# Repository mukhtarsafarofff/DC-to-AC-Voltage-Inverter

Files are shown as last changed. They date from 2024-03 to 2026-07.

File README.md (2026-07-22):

(ENG)  This Power Inverter is a backup power supply using a 12V battery that will invert it to 220V AC. Using this Power Inverter we can use your appliances like TV, Radio, Audio system as well as lightings like a bulb, fluorescent, etc. This inverter has three main parts: 12V Battery, Inverter Board, and Centertapped Transformer. This inverter has a Tl494 PWM IC that provides a pulse with modulation, the two output pins of this PWM ic are responsible for ON state and OFF state of the power mosfet. Power Mosfet (IRFZ44N) i is a specific type of metal–oxide–semiconductor field-effect transistor designed to handle significant power levels. The drain terminal of the MOSFET is connected to the center-tapped of the transformer, the power MOSFET is ON and OFF synchronize to the PWM IC output pin, and the Centertapped transformer are in STEP UP condition (from 12V DC to 22OV AC). The power of inverter are dependent to the power capacity of the battery and transformer. This inverter has Reverse polarity protection, wherein if you connected the battery in the WRONG WAY the inverter is safe, because of this 1N4148 (1A). 1N4148 diode has a lower voltage drop compared to the other diode. Therefore the power losses are significantly lower compared to other diodes. This inverter is in the square waveform, therefore you can only use it in resistive load like a bulb, and also you can use it and an electronic device like TV's.

(DEU)  Dieser Power Inverter ist eine Notstromversorgung, die eine 12V Batterie verwendet und diese in 220V AC umwandelt. Mit diesem Power Inverter können Sie Ihre Geräte wie Fernseher, Radio, Audiosystem sowie Beleuchtungen wie Glühbirnen,Leuchtstofflampen usw. nutzen.  Der Inverter besteht aus drei Hauptteilen: 12V Batterie, Inverterplatine und mittelanzapfender Transformator.  Dieser Inverter verfügt über einen TL494 PWM IC, der eine Pulsweitenmodulation bereitstellt. Die zwei Ausgangspins dieses PWM ICs steuern den ON- und OFF-Zustand des Power-Mosfets. Der Power Mosfet (IRFZ44N) ist eine spezielle Art von Metalloxid-Halbleiter-Feldeffekttransistor, der für hohe Leistungsniveaus ausgelegt ist. Das Drain-Terminal des MOSFET ist mit der Mittelanzapfung des Transformators verbunden, der Power MOSFET schaltet synchron zu den Ausgangspins des PWM IC ein und aus, und der mittelanzapfende Transformator befindet sich im STEP-UP-Zustand (von 12V DC zu 220V AC). Die Leistung des Inverters hängt von der Kapazität der Batterie und des Transformators ab. Dieser Inverter hat einen Verpolungsschutz, wodurch er sicher bleibt, wenn Sie die Batterie falsch anschließen, dank der Diode 1N4148 (1A), die einen geringeren Spannungsabfall im Vergleich zu anderen Dioden aufweist. Daher sind die Leistungsverluste im Vergleich zu anderen Dioden deutlich geringer. Dieser Inverter erzeugt eine quadratische Wellenform und ist daher nur für ohmsche Lasten wie Glühbirnen oder auch für elektronische Geräte wie Fernseher geeignet.

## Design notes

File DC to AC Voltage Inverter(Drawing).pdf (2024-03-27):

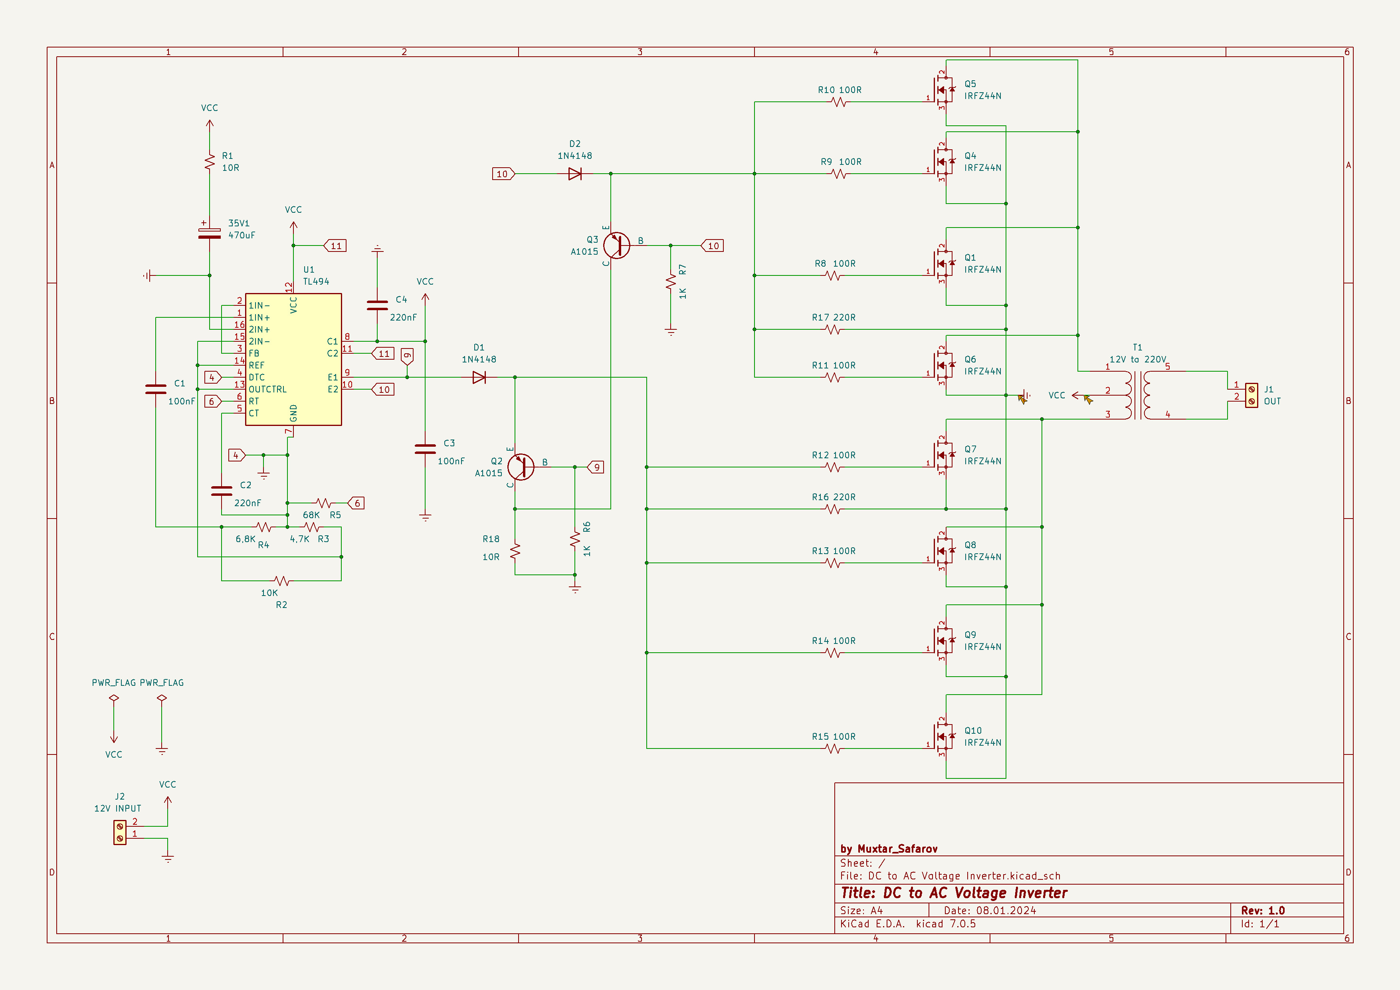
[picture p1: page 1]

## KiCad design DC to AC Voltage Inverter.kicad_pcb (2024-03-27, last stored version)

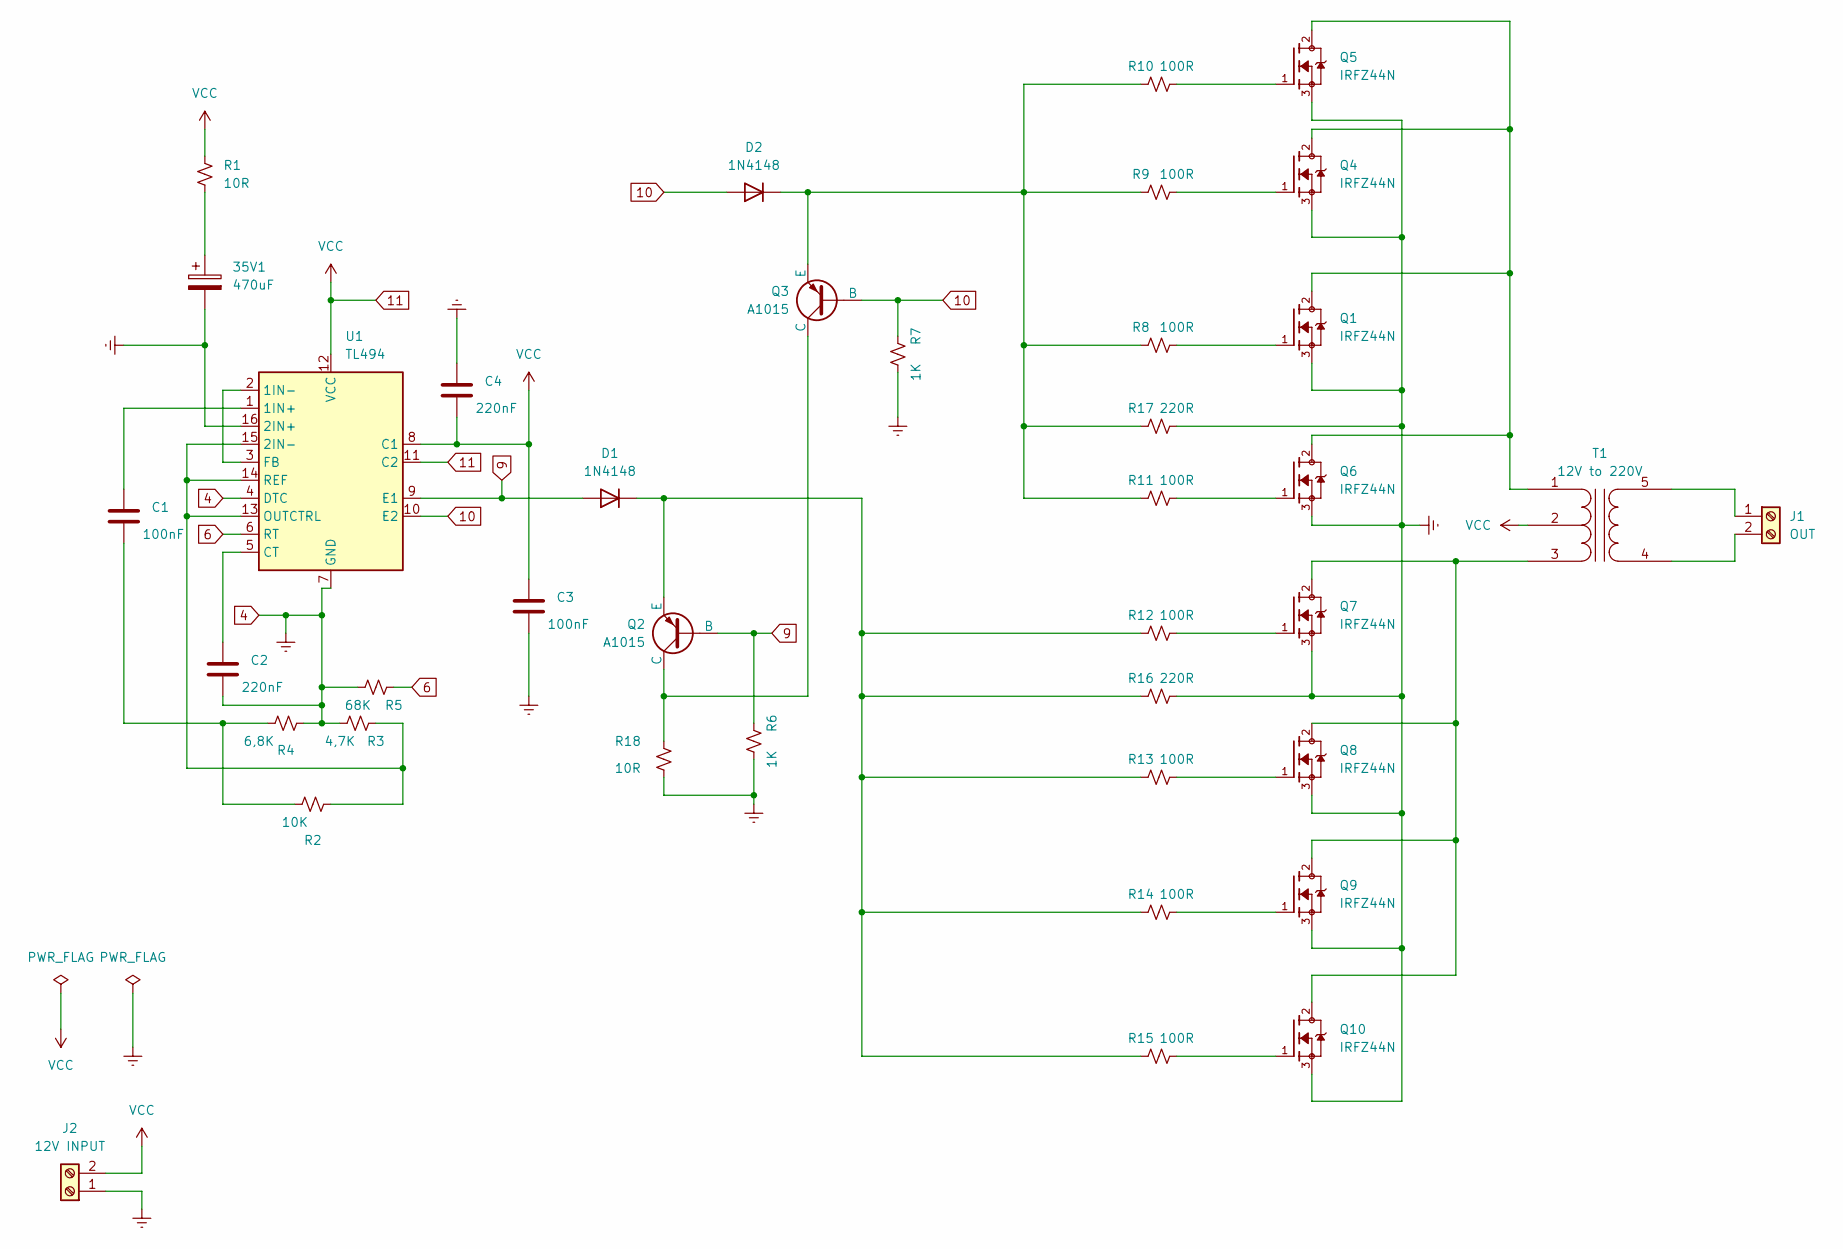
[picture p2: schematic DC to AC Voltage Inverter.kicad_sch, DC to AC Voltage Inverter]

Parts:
35V1: 470uF; CP_Radial_D10.0mm_P7.50mm
C1, C3: 100nF; C_Disc_D7.5mm_W5.0mm_P7.50mm
C2, C4: 220nF; C_Disc_D7.5mm_W5.0mm_P7.50mm
D1, D2: 1N4148; D_DO-35_SOD27_P7.62mm_Horizontal
J1: OUT; TerminalBlock_bornier-2_P5.08mm
J2: 12V INPUT; TerminalBlock_bornier-2_P5.08mm
Q1, Q4, Q5, Q6, Q7, Q8, Q9, Q10: IRFZ44N; TO254P1016X419X2286-3; PARTREV 09/21/10
Q2, Q3: A1015; TO254P1016X419X2286-3
R1, R18: 10R; R_Axial_DIN0516_L15.5mm_D5.0mm_P25.40mm_Horizontal
R2: 10K; R_Axial_DIN0516_L15.5mm_D5.0mm_P25.40mm_Horizontal
R3: 4,7K; R_Axial_DIN0516_L15.5mm_D5.0mm_P25.40mm_Horizontal
R4: 6,8K; R_Axial_DIN0516_L15.5mm_D5.0mm_P25.40mm_Horizontal
R5: 68K; R_Axial_DIN0516_L15.5mm_D5.0mm_P25.40mm_Horizontal
R6, R7: 1K; R_Axial_DIN0516_L15.5mm_D5.0mm_P25.40mm_Horizontal
R8, R9, R10, R11, R12, R13, R14, R15: 100R; R_Axial_DIN0516_L15.5mm_D5.0mm_P25.40mm_Horizontal
R16, R17: 220R; R_Axial_DIN0516_L15.5mm_D5.0mm_P25.40mm_Horizontal
T1: 12V to 220V; Transformer_Toroid_Horizontal_D18.0mm
U1: TL494; DIP-16_W7.62mm

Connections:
4: 35V1.2, C2.2, C3.2, C4.1, J2.1, Q1.3, Q4.3, Q5.3, Q6.3, Q7.3, Q8.3, Q9.3, Q10.3, R3.1, R4.2, R5.1, R6.1, R7.1, R16.1, R17.1, R18.1, U1.4 (DTC), U1.7 (GND), U1.16 (2IN+)
6: R5.2, U1.6 (RT)
9: D1.2 (A), Q2.2 (B), R6.2, U1.9 (E1)
10: D2.2 (A), Q3.2 (B), R7.2, U1.10 (E2)
11: C3.1, C4.2, J2.2, R1.1, T1.2 (PM), U1.8 (C1), U1.11 (C2), U1.12 (VCC)
unnamed: 35V1.1, R1.2
unnamed: C1.2, R2.1, R4.1
unnamed: D1.1 (K), Q2.3 (E), R12.2, R13.2, R14.2, R15.2, R16.2
unnamed: D2.1 (K), Q3.3 (E), R8.2, R9.2, R10.2, R11.2, R17.2
unnamed: J1.1, T1.5 (S2)
unnamed: J1.2, T1.4 (S1)
unnamed: Q1.1, R8.1
unnamed: Q2.1 (C), Q3.1 (C), R18.2
unnamed: Q4.1, R9.1
unnamed: Q5.1, R10.1
unnamed: Q6.1, R11.1
unnamed: Q7.1, R12.1
unnamed: Q8.1, R13.1
unnamed: Q9.1, R14.1
unnamed: Q10.1, R15.1
unnamed: Q1.2, Q4.2, Q5.2, Q6.2, T1.1 (PR1)
unnamed: Q7.2, Q8.2, Q9.2, Q10.2, T1.3 (PR2)
unnamed: C1.1, U1.1 (1IN+)
unnamed: U1.2 (1IN-), U1.3 (FB)
unnamed: R2.2, R3.2, U1.13 (OUTCTRL), U1.14 (REF), U1.15 (2IN-)
unnamed: C2.1, U1.5 (CT)

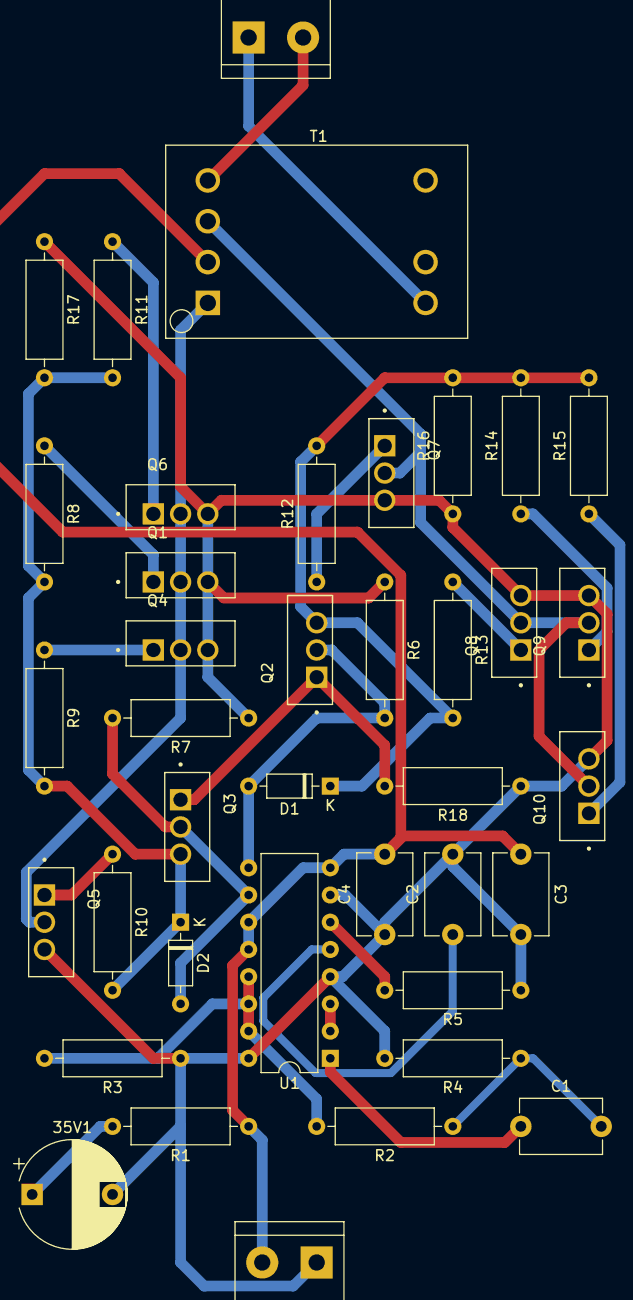
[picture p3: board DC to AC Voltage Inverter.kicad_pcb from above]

Board: 2 copper layers, 39 parts (0 on the bottom side), 26 nets.
